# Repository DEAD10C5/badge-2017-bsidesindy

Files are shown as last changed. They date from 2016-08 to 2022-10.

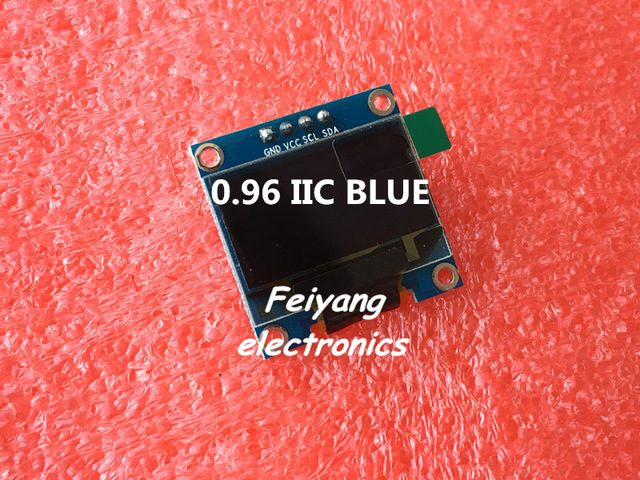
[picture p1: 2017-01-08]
image/1pcs-0-96-blue-0-96-inch-OLED-module-New-128X64-OLED-LCD-LED-Display-Module.jpg_640x640.jpg

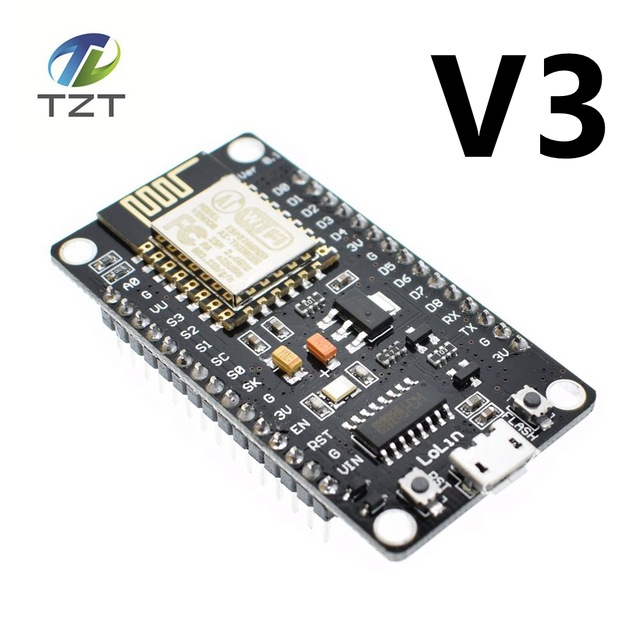
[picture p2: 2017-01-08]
image/1PCS-Wireless-module-CH340-NodeMcu-V3-Lua-WIFI-Internet-of-Things-development-board-based-ESP8266.jpg_640x640.jpg

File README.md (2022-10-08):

## BSidesIndy 2017 Badge



We did this as a workshop during @indybsides in March 2017.

See the wiki for more information.

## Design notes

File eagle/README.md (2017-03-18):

###
https://learn.sparkfun.com/tutorials/using-eagle-schematic

### push buttons
 https://www.sparkfun.com/products/97

I have ordered a bunch of this push buttons. These push buttons fit easily into a breadboard. However, now that I have my prototype working and I am making a schematic in Eagle, I have no idea what the dimensions are to make my switch component in Eagle. It is very frustrating and time wasting.
 M-Short / about 2 years ago /  1
This switch is actually in our Eagle libraries. Check under the Electromagnetic/Switch-Momentary-2 section. It should be the first one (Description: Omron switch). Or internal part number is SWCH-8441, as long as you have that one selected you should be good. Feel free to email techsupport if you have any other questions or ever need more information.

### esp-8266

* Clone the repo :

https://github.com/nodemcu/nodemcu-devkit-v1.0

Copy the file ESP12E_DEVKIT.lbr from the repo to the folder /Applications/EAGLE-7.5.0/lbr

Open the brd file, click "Library" then "use"

### OLED SSD-1306

http://learn.acrobotic.com/tutorials/post/esp8266-oled-display-using-i2c

### resistors (using internal instead)

http://electronics.stackexchange.com/questions/65015/resistor-and-capacitor-package-types-eagle-cad

Resistors with different power ratings have different standard sizes (for example, 1/8W vs 1/4W). Likewise for capacitors, the part you need to use depends on the type of capacitor (monolithic, ceramic, electrolytic, etc) and the capacitance and voltage ratings. Assuming you are looking at the RCL library, 0207/10 simply means the body of the resistor is 2mm x 7mm and the hole to hole spacing is 10mm. Similarly C050-035x075 means 5mm hole spacing, 3.5mm x 7.5mm outline. You have to figure out (with calipers, for example) if this will work with the parts you are planning to use.

http://www.instructables.com/id/Draw-Electronic-Schematics-with-CadSoft-EAGLE/step5/Add-resistors/

### battery holder

https://www.sparkfun.com/products/13113
Note: This part can be found in the Electromechanical Eagle library under ‘Battery18650’.

### some notes

One thing you can do is print the board layout at 1:1 scale on paper before sending it out to the fab to see if the parts fit. You can catch common errors this way.

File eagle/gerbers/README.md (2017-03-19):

## Create Gerber files
http://www.build-electronic-circuits.com/gerber-file/

## view gerber files
http://www.gerber-viewer.com/

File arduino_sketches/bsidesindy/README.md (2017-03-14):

** Arduino code for Nodemcu esp-12e
https://www.arduino.cc/en/Tutorial/TFTPong

http://www.coagula.org/albedo/tutorial-manage-menu-and-lcd-display-with-arduino/

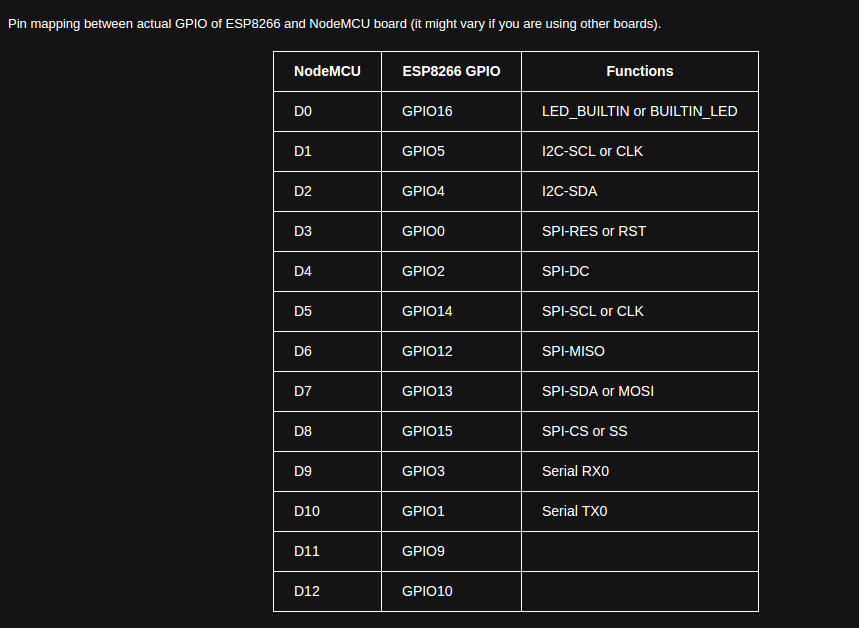
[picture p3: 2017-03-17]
image/esp12-e_pinout.png

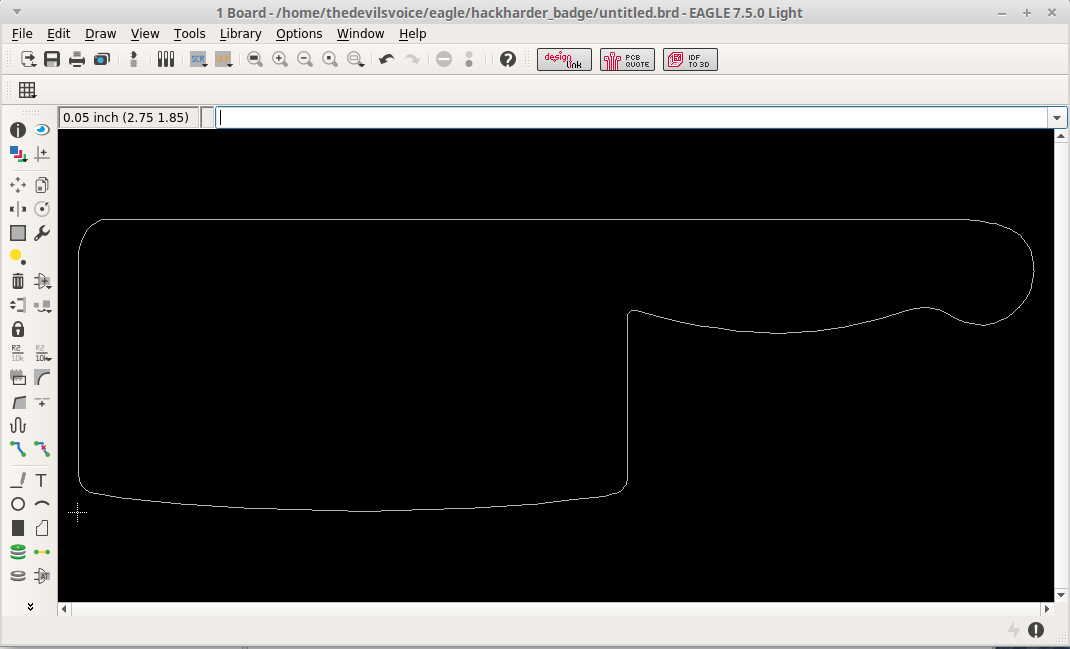
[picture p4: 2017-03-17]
image/board-1.png

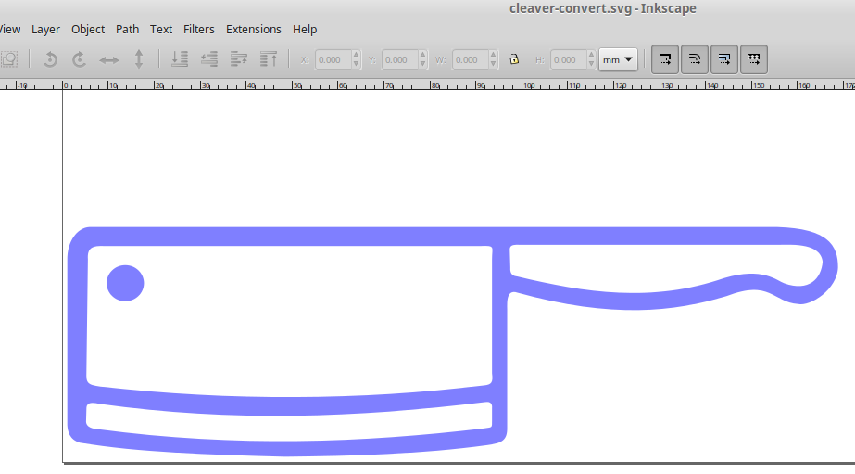
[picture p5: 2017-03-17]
image/Screenshot-1.png

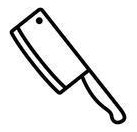
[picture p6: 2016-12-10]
image/cleaver.jpg

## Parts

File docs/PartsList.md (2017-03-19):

# Required Badge parts

use the links provded to order the ESP8266 and the OLED so it matches up to the holes in the PCB.
The battery and case are available on ebay. These will be stuck to the back of the board using the VHB tape, which is available from amazon or target stores.

| count | part | est cost |
| --- | --- | --- |
| 1 | [NodeMCU LUA WiFi Internet Development Board V3 Wireless module Based CH340 ESP8266 EK1677 Arduino Compatible]( https://smile.amazon.com/gp/product/B010O1G1ES/ )| $9 |
| 1 | [ OLED screen](https://www.amazon.com/gp/product/B00O2KDQBE) | $9 | 
| 4 | [switches]( http://www.digikey.com/product-detail/en/te-connectivity-alcoswitch-switches/1825910-6/450-1650-ND/1632536 ) | $0.10 |
| 1 | [battery holder](https://www.sparkfun.com/products/13113) | $ 0.75 |

# Prototyping Supplies

These are optional pieces, only one breadboard is needed. 

| count | part | est cost |
| --- | --- | --- |
| 1 | [ Large breadboard] ( https://www.adafruit.com/products/443 )  | $20 |
| 1 | [ VHB tape for battery/back of OLED ] (https://www.amazon.com/Tape-RP32-width-length-Roll/dp/B007Y7E0CQ) | $3 |
| 1 | micro USB cable to program ESP8266 | $5 | 
| 1 | [ small breadboard] (  https://www.adafruit.com/products/64 ) | $5 | 
| 1 | [ Jumper wires] ( https://www.adafruit.com/products/153 ) | $6 | 

# Alternate Sources

| count | part | est cost |
| --- | --- | --- |
| 1 | [Blue 0.96 inch 128X64 OLED LCD LED Display Module For arduino IIC I2C Communicate] (https://m.aliexpress.com/s/item/32697483355.html ) | $3 | 
| 1 | 18650 3.7V/12000mAh Rechargeable Li-ion Battery | $5 |

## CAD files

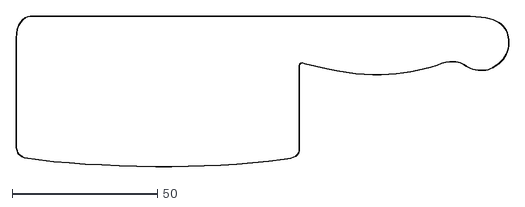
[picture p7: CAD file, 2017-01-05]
image/cleaver-outline.dxf
169.7 x 51.9

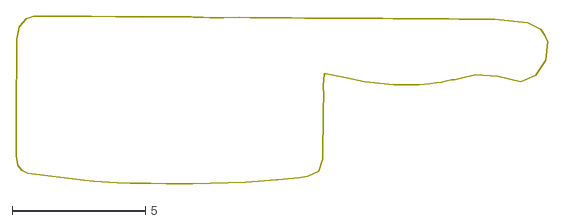
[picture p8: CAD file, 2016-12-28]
image/cleaver-ki2.dxf
20.0 x 6.30

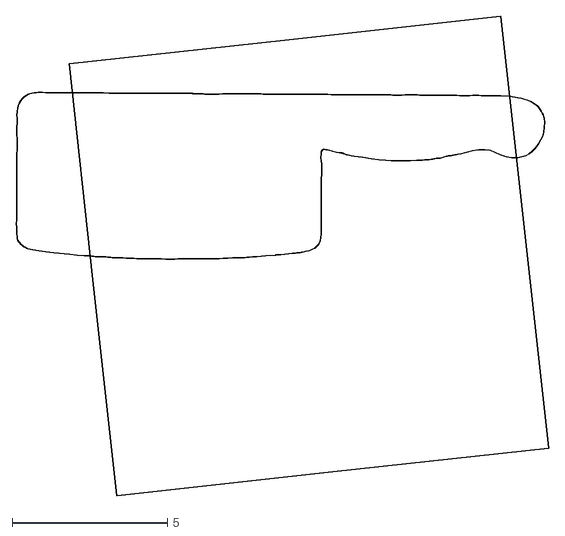
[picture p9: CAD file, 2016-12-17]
image/cleaver.dxf
17.2 x 15.5

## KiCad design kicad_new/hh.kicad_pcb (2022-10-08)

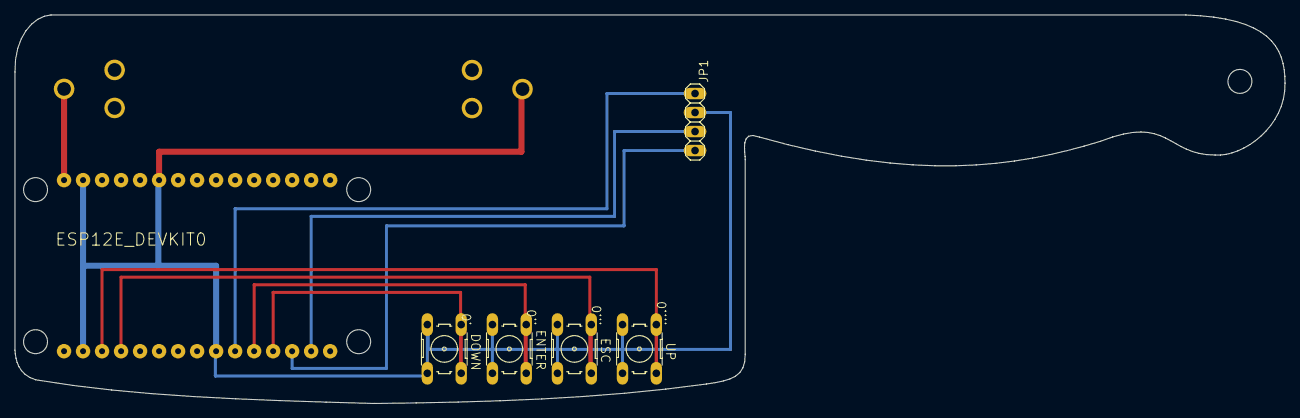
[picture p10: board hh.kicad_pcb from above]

Board: 6 copper layers, 169.7 x 51.9 mm, 8 parts (1 on the bottom side), 9 nets.

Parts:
.0, ..0, ...0, ....0: B3F-10XX
@HOLE0: (no value)
BT1: BATTERY_18650-HOLDER
ESP12E_DEVKIT0: ESP12E_DEVKIT
JP1: OLED; 1X04

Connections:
unnamed: .0.3, .0.4, ..0.3, ..0.4, ...0.3, ...0.4, ....0.3, ....0.4, BT1.GND@1, ESP12E_DEVKIT0.GND@0, ESP12E_DEVKIT0.GND@1, ESP12E_DEVKIT0.GND@2, ESP12E_DEVKIT0.GND@3, JP1.2
unnamed: .0.1, .0.2, ESP12E_DEVKIT0.D3
unnamed: ESP12E_DEVKIT0.3V3@1, JP1.1
unnamed: BT1.PWR@1, ESP12E_DEVKIT0.VIN
unnamed: ESP12E_DEVKIT0.D1, JP1.3
unnamed: ESP12E_DEVKIT0.D2, JP1.4
unnamed: ..0.1, ..0.2, ESP12E_DEVKIT0.D4
unnamed: ...0.1, ...0.2, ESP12E_DEVKIT0.RX
unnamed: ....0.1, ....0.2, ESP12E_DEVKIT0.TX

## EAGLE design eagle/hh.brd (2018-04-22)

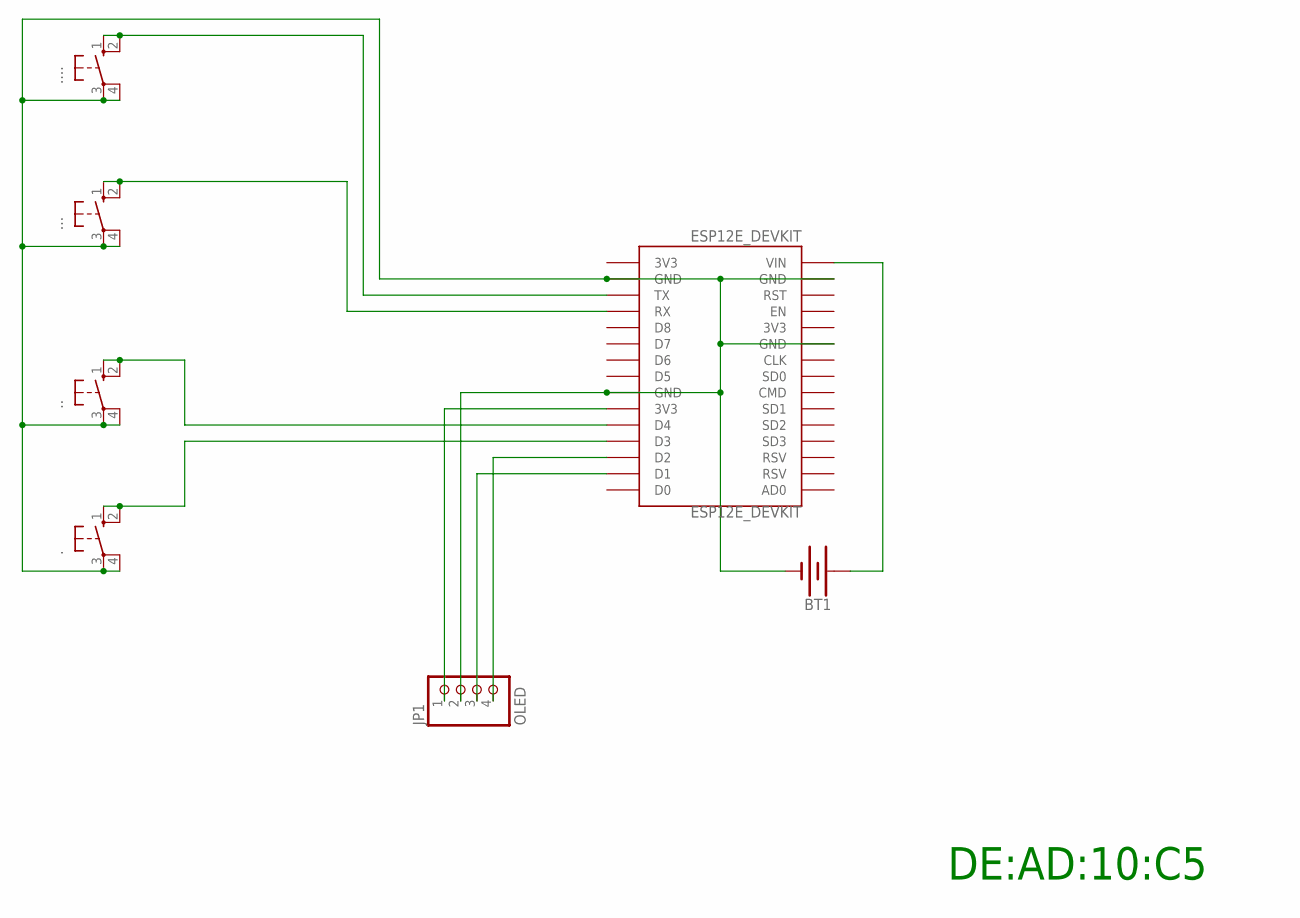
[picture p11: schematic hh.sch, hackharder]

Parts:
., .., ..., ....: 10-XX; B3F-10XX
BT1: BATTERY-18650; BATTERY_18650-HOLDER
ESP12E_DEVKIT: ESP12E_DEVKIT
JP1: OLED; 1X04

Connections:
unnamed: ..3, ..4 (P1), ...3, ...4 (P1), ....3, ....4 (P1), .....3, .....4 (P1), BT1.GND@1 (-), ESP12E_DEVKIT.GND@0 (GND), ESP12E_DEVKIT.GND@1 (GND), ESP12E_DEVKIT.GND@2 (GND), ESP12E_DEVKIT.GND@3 (GND), JP1.2
unnamed: ..1 (S), ..2 (S1), ESP12E_DEVKIT.D3
unnamed: ESP12E_DEVKIT.3V3@1 (3V3), JP1.1
unnamed: BT1.PWR@1 (+), ESP12E_DEVKIT.VIN
unnamed: ESP12E_DEVKIT.D1, JP1.3
unnamed: ESP12E_DEVKIT.D2, JP1.4
unnamed: ...1 (S), ...2 (S1), ESP12E_DEVKIT.D4
unnamed: ....1 (S), ....2 (S1), ESP12E_DEVKIT.RX
unnamed: .....1 (S), .....2 (S1), ESP12E_DEVKIT.TX

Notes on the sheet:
DE:AD:10:C5

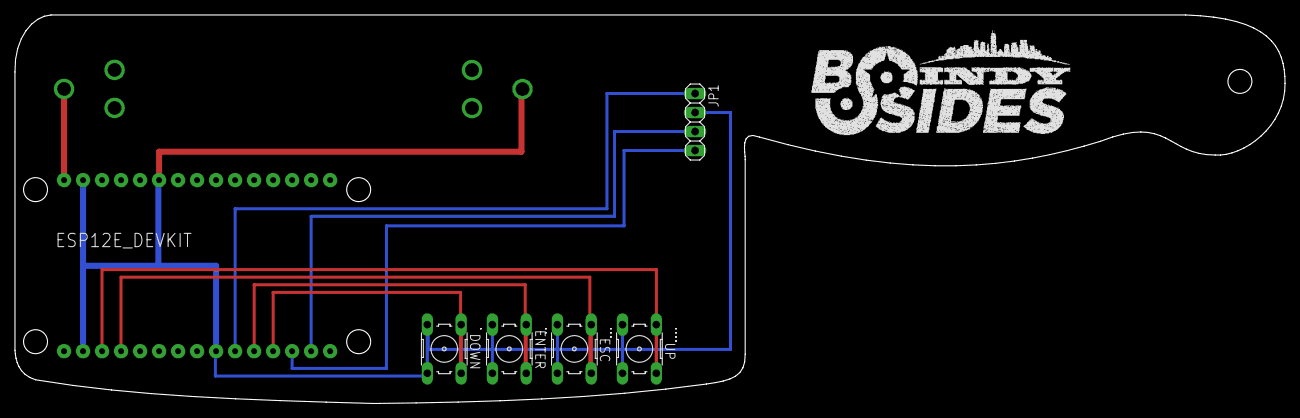
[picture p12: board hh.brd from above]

Board: 2 copper layers, 169.7 x 51.9 mm, 7 parts (1 on the bottom side), 9 nets.

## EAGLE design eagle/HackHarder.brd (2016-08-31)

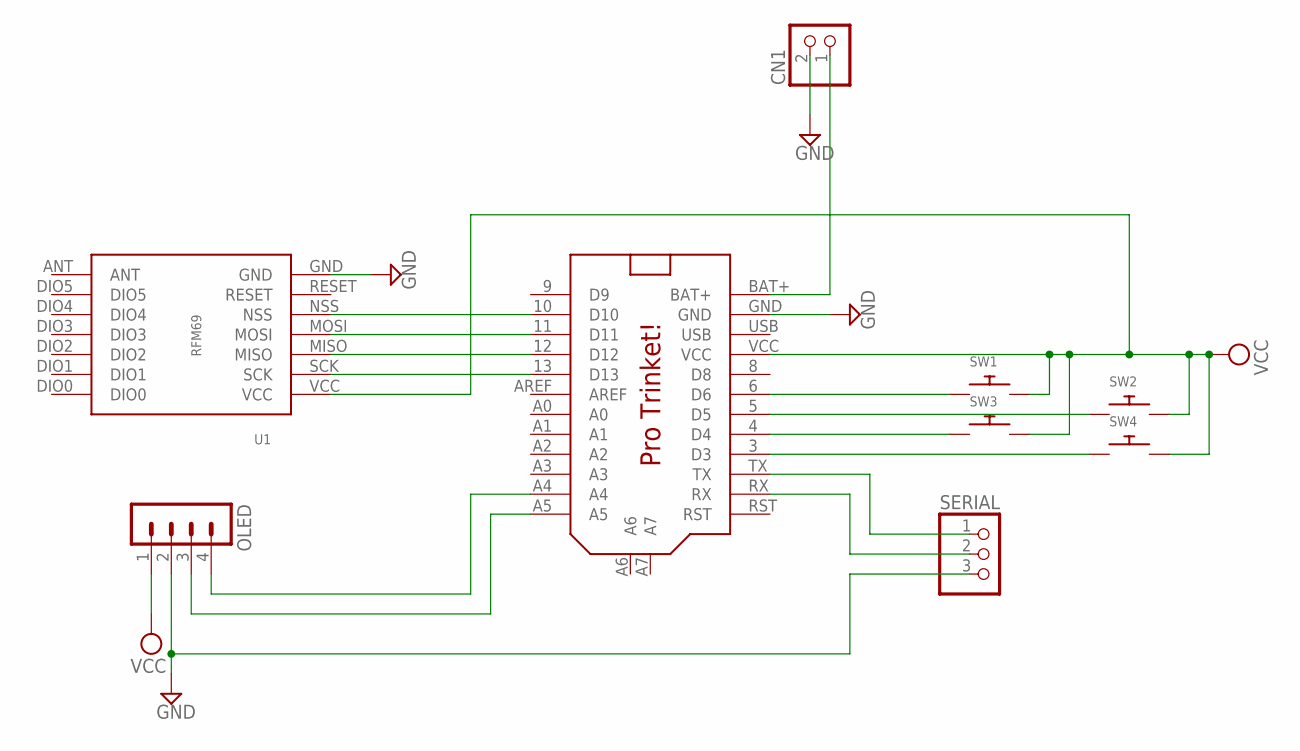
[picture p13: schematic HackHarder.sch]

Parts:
CN1: JST_2PIN-SMT-RA; JST-PH-2-SMT-RA
MCU1: PRO_TRINKET; PROTRINKET
OLED: MA04-1
SERIAL: PINHD-1X3; 1X03
SW1, SW2, SW3, SW4: SWITCH_PUSHBUTTONEVQ-PE; TACT_PANA-EVQ
U1: RFM69HW; RFM69_PADS

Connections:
G$1: CN1.2 (1), MCU1.GND, OLED.2, SERIAL.3, U1.GND
unnamed: CN1.1 (2), MCU1.BAT+
unnamed: MCU1.A5, OLED.3
unnamed: MCU1.A4, OLED.4
unnamed: MCU1.11 (D11), U1.MOSI
unnamed: MCU1.12 (D12), U1.MISO
unnamed: MCU1.13 (D13), U1.SCK
unnamed: MCU1.10 (D10), U1.NSS
unnamed: MCU1.6 (D6), SW1.P$1
unnamed: MCU1.5 (D5), SW2.P$1
unnamed: MCU1.4 (D4), SW3.P$1
unnamed: MCU1.3 (D3), SW4.P$1
unnamed: MCU1.TX, SERIAL.1
unnamed: MCU1.RX, SERIAL.2
USB: MCU1.USB
VCC: MCU1.VCC, OLED.1, SW1.P$2, SW2.P$2, SW3.P$2, SW4.P$2, U1.VCC

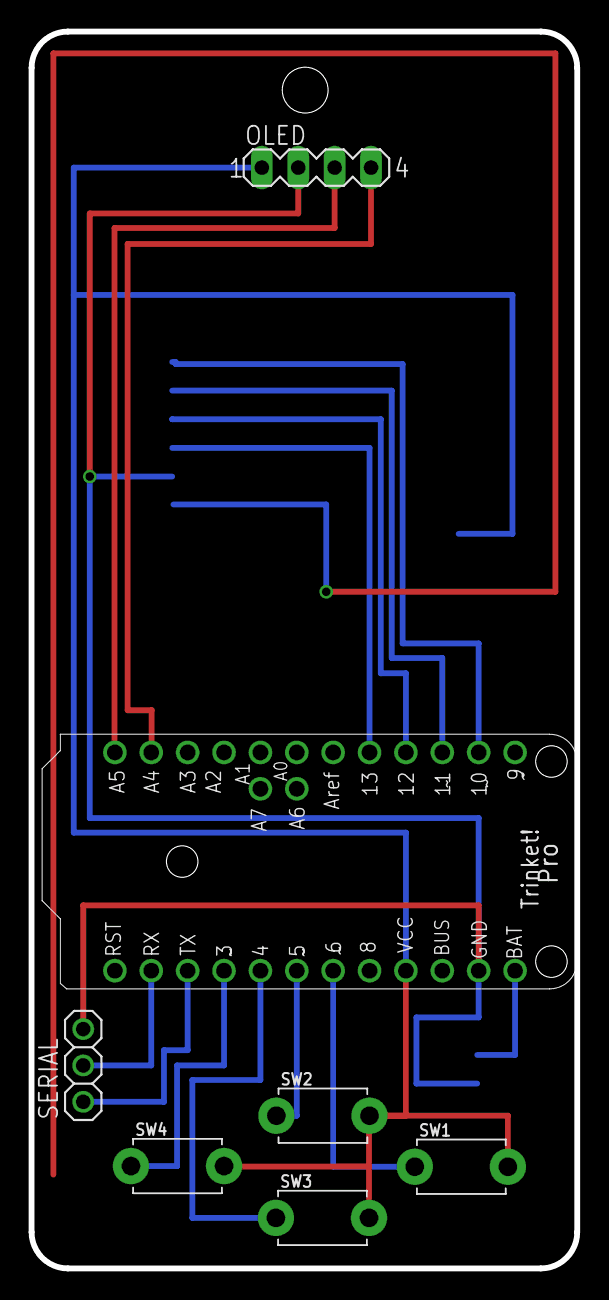
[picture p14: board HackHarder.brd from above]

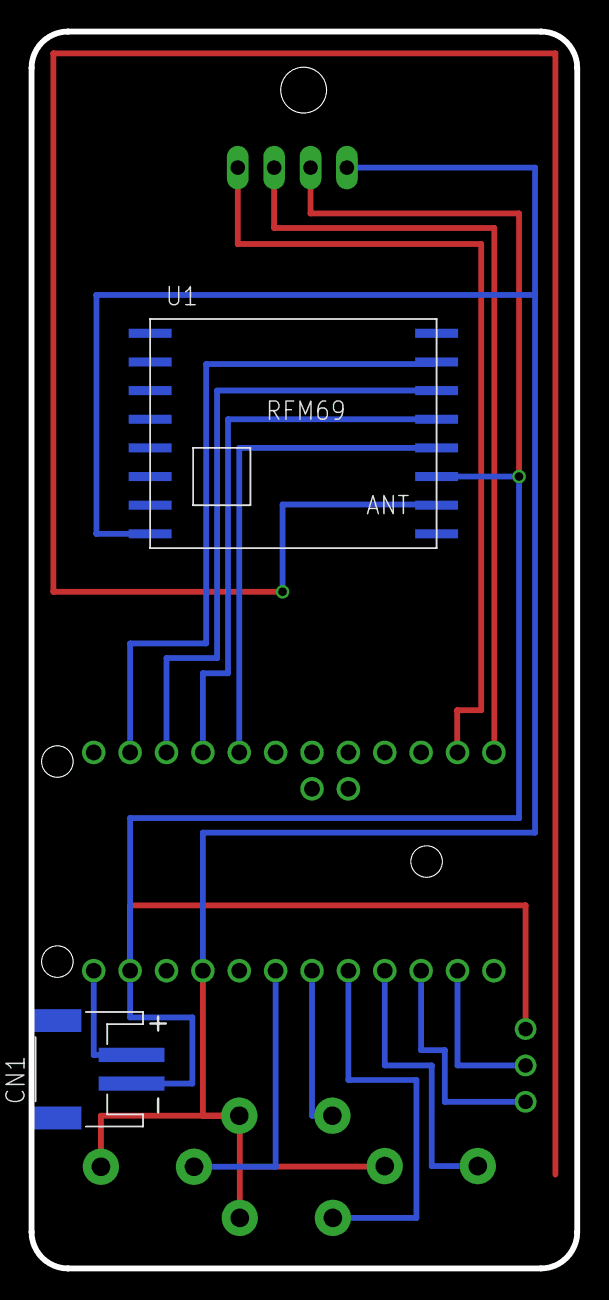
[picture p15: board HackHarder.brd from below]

Board: 2 copper layers, 38.1 x 86.4 mm, 9 parts (2 on the bottom side), 15 nets.

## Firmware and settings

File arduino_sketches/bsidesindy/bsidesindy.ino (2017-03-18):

/* 
 *   ____  _           _       _         _     _           
 *  / __ \(_)_ __   __| |_   _| |__  ___(_) __| | ___  ___ 
 * / / _` | | '_ \ / _` | | | | '_ \/ __| |/ _` |/ _ \/ __|
 *| | (_| | | | | | (_| | |_| | |_) \__ \ | (_| |  __/\__ \
 * \ \__,_|_|_| |_|\__,_|\__, |_.__/|___/_|\__,_|\___||___/
 *  \____/               |___/                             
 *
 *              H dlh dcaego uz aego ak.vol,vohs
 */
#include <ESP8266WiFi.h>
#include "Adafruit_MQTT.h"
#include "Adafruit_MQTT_Client.h"
// These next 4 are to drive the OLED
#include <SPI.h>
#include <Wire.h>
#include <Adafruit_GFX.h>
#include <Adafruit_SSD1306.h>


// Defines for LED pulse code
#define BRIGHT    350     //max led intensity (1-500)
#define INHALE    1250    //Inhalation time in milliseconds.
#define PULSE     INHALE*1000/BRIGHT
#define REST      100    //Rest Between Inhalations.

/*
 * Adafruit.io Setup 
 * 
 * Use this to connect to https://io.adafruit.com/
 * rather than a local MQTT service. 
 * 
 * Create an ESP8266 WiFiClient class to connect to the MQTT server. 
 * WiFiClient client; or... use WiFiFlientSecure for SSL
 * 
 */
#define AIO_SERVER "io.adafruit.com"
#define AIO_SERVERPORT  8883                   // use 8883 for SSL
#define AIO_USERNAME    ""
#define AIO_KEY         ""
WiFiClientSecure client;
// Setup the MQTT client class by passing in the WiFi client and MQTT server and login details.
Adafruit_MQTT_Client mqtt(&client, AIO_SERVER, AIO_SERVERPORT, AIO_USERNAME, AIO_KEY);



/* 
 * Global Variables Setup 
 */
char handle[ ] = "p0lr";
char input[ ] = "";
bool inputComplete = false;
const char* ssid = "batpack";
const char* password = "batpack";
//const char* mqtt_server = "broker.mqttdashboard.com";
//const char* mqtt_server = "iot.eclipse.org";
//const char* mqtt_server = "io.adafruit.com"
#define OLED_RESET 2
Adafruit_SSD1306 display(OLED_RESET);
int switchPin1 = D9;              
int switchPin2 = D10;
int switchPin3 = D4;
int switchPin4 = D3;

/****************************** Feeds ***************************************/
Adafruit_MQTT_Publish toServer = Adafruit_MQTT_Publish(&mqtt, AIO_USERNAME "/feeds/toServer");
Adafruit_MQTT_Subscribe toBadge = Adafruit_MQTT_Subscribe(&mqtt, AIO_USERNAME "/feeds/toBadge");

/*************************** Sketch Code ************************************/

/*  
 * Bug workaround for Arduino 1.6.6, it seems to need a function declaration 
 * for some reason (only affects ESP8266, likely an arduino-builder bug).
 */
void MQTT_connect();

#if (SSD1306_LCDHEIGHT != 32)
#error("Height incorrect, please fix Adafruit_SSD1306.h!");
#endif

void setup() {
  Serial.begin(115200);
  delay(10);
  setup_display();
  setup_wifi();
  pinMode(switchPin1,       INPUT);  // Set the switch pin as input
  digitalWrite(switchPin1,  HIGH);   // turn on pull up resistor
  pinMode(switchPin2,       INPUT);
  digitalWrite(switchPin2,  HIGH);
  pinMode(switchPin3,       INPUT);
  digitalWrite(switchPin3,  HIGH);
  pinMode(switchPin4,       INPUT);
  digitalWrite(switchPin4,  HIGH);
  pinMode(LED_BUILTIN,      OUTPUT); // initialize the on-board LED
  digitalWrite(LED_BUILTIN, HIGH);   // turn LED off
  mqtt.subscribe(&toBadge);          // Setup MQTT subscription for onoff feed.
}

void loop() {
  int status;
  display.setCursor(0, 0);
  display.println("@indybsides");
  display.display();
  
  MQTT_connect();
  Adafruit_MQTT_Subscribe *subscription;
  while ((subscription = mqtt.readSubscription(5000))) {
    if (subscription == &toBadge) {
      Serial.println((char *)toBadge.lastread);
    }
  }

  // check if the button is pressed
  if (digitalRead(switchPin1) == LOW) {               
    button_press("1");
  } else if (digitalRead(switchPin2) == LOW) {
    button_press("2");
  } else if (digitalRead(switchPin3) == LOW) {
    button_press("3");
  } else if (digitalRead(switchPin4) == LOW) {
    button_press("4");
  }
  else {

    Serial.println("Nothing just happened");
  }
  
  //Check to see if there is any serial data inbound
  if (Serial.available() > 0) {
  // read the incoming byte:
    char inChar[ ] = "";
    inChar[0] = (char)Serial.read();
    strcat(input, inChar);
    if (inChar[0] == '\n') {
      inputComplete = true;
    }
  }

  // Now we can publish stuff!
  if (inputComplete) {
    //digitalWrite(LED_BUILTIN, HIGH);
    char post[ ] = "";
    strcat(post, handle);
    strcat(post, ": ");
    strcat(post, "Hello, World!");
    Serial.println(post);
    if (! toServer.publish(post)) {
      Serial.println(F("Failed"));
    } else {
//      input = " ";
      inputComplete = false;
    }
  }
  // ping the server to keep the mqtt connection alive
  // NOT required if you are publishing once every KEEPALIVE seconds
  if(! mqtt.ping()) {
    mqtt.disconnect();
  }
}

void setup_display() {
  // by default, we'll generate the high voltage from the 3.3v line 
  // internally! (neat!)
  // initialize with the I2C addr 0x3C (for the 128x32)
  display.begin(SSD1306_SWITCHCAPVCC, 0x3C);  
  display.clearDisplay();
  display.setTextSize(1);
  display.setTextColor(WHITE);
  display.setCursor(0,0);  
}

void setup_wifi() {
  delay(100);
  Serial.print("Connecting to ");
  Serial.println(ssid);
  WiFi.begin(ssid, password);
    while (WiFi.status() != WL_CONNECTED) 
    {
      delay(500);
      Serial.print(".");
    }
  randomSeed(micros());
  String msg="WiFi Connected!\nIP address: " + WiFi.localIP();
  Serial.println(msg);
  display.println(msg);
  display.display();
}

/* 
 * Function to connect and reconnect as necessary to the MQTT server.
 * Should be called in the loop function and it will take care if connecting.
 * 
 */
void MQTT_connect() {
  int8_t ret;

  // Stop if already connected.
  if (mqtt.connected()) {
    return;
  }

  String msg="Connecting to MQTT... ";
  Serial.println(msg);
  display.println(msg);
  display.display();
  
  uint8_t retries = 3;
  while ((ret = mqtt.connect()) != 0) { // connect will return 0 for connected
       Serial.println(mqtt.connectErrorString(ret));
       Serial.println("Retrying MQTT connection in 5 seconds...");
       mqtt.disconnect();
       delay(5000);  // wait 5 seconds
       retries--;
       if (retries == 0) {
         // basically die and wait for WDT to reset me
         while (1);
       }
  }
  msg = "MQTT Connected!";
  Serial.println(msg);
  display.println(msg);
  display.display();
  
}

void button_press(String button_num) {
  //digitalWrite(LED_BUILTIN, LOW);   // turn LED on
  String msg = "Button " + button_num + " pressed";
  Serial.println(msg);
  display.println(msg);
  display.display();
  led_half_breath();
  delay(300);
  //digitalWrite(LED_BUILTIN, HIGH);  // turn LED off
  digitalWrite(switchPin1, HIGH);
  digitalWrite(switchPin2, HIGH);
  digitalWrite(switchPin3, HIGH);
  digitalWrite(switchPin4, HIGH);
  delay(200);
  display.setCursor(0, 4);
  display.clearDisplay();
  display.display();
}

/*
 * Pulse the Internal LED
 */
void led_breath() {
     //ramp increasing intensity, Inhalation: 
  for (int i=1;i<BRIGHT;i++){
    digitalWrite(LED_BUILTIN, LOW);          // turn the LED on.
    delayMicroseconds(i*10);         // wait
    digitalWrite(LED_BUILTIN, HIGH);         // turn the LED off.
    delayMicroseconds(PULSE-i*10);   // wait
    delay(0);                        //to prevent watchdog firing.
  }
}

/*
 * Half-pulse the internal LED
 */
void led_half_breath() {
  
  //ramp decreasing intensity, Exhalation (half time):
  for (int i=BRIGHT-1;i>0;i--){
    digitalWrite(LED_BUILTIN, LOW);          // turn the LED on.
    delayMicroseconds(i*10);          // wait
    digitalWrite(LED_BUILTIN, HIGH);         // turn the LED off.
    delayMicroseconds(PULSE-i*10);  // wait
    i--;
    delay(0);                        //to prevent watchdog firing.
  }
  delay(REST);                       //take a rest...
}

/***************************************************
  Adafruit MQTT Library ESP8266 Example

  Must use ESP8266 Arduino from:
    https://github.com/esp8266/Arduino

  Works great with Adafruit's Huzzah ESP board & Feather
  ----> https://www.adafruit.com/product/2471
  ----> https://www.adafruit.com/products/2821

  Adafruit invests time and resources providing this open source code,
  please support Adafruit and open-source hardware by purchasing
  products from Adafruit!

  Written by Tony DiCola for Adafruit Industries.
  MIT license, all text above must be included in any redistribution
 ********************************************************************
This is an example for our Monochrome OLEDs based on SSD1306 drivers

  Pick one up today in the adafruit shop!
  ------> http://www.adafruit.com/category/63_98

This example is for a 128x32 size display using I2C to communicate
3 pins are required to interface (2 I2C and one reset)

Adafruit invests time and resources providing this open source code, 
please support Adafruit and open-source hardware by purchasing 
products from Adafruit!

Written by Limor Fried/Ladyada  for Adafruit Industries.  
BSD license, check license.txt for more information
All text above, and the splash screen must be included in any redistribution
*********************************************************************/

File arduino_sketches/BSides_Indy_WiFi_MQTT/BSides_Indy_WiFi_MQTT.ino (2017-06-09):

#include "SSD1306.h" // alias for `#include "SSD1306Wire.h"`
#include "ESP8266WiFi.h"
#define UP 1
#define ESC 3
#define ENTER 2
#define DOWN 0
SSD1306 display(0x3c, D2, D1);

void setup() {
  display.init();
  display.flipScreenVertically();
  WiFi.mode(WIFI_STA);
  WiFi.disconnect();
  pinMode(UP, INPUT_PULLUP);
  pinMode(ESC, INPUT_PULLUP);
  pinMode(ENTER, INPUT_PULLUP);
  pinMode(DOWN, INPUT_PULLUP);
}

void loop() {
  if(WiFi.status() == 3) {

  }
  else {
    WiFi.begin("badger", "!dongle!");
    while (WiFi.status() != 3) {
      display.clear();
      display.setTextAlignment(TEXT_ALIGN_LEFT);
      display.setFont(ArialMT_Plain_10);
      display.drawString(0, 0, "Connecting to WiFi");
      display.display();
    }
    display.clear();
    display.setTextAlignment(TEXT_ALIGN_LEFT);
    display.setFont(ArialMT_Plain_10);
    display.drawString(0, 0, "WiFi Connected");
    display.drawString(0, 10, String(WiFi.localIP()[0]) + "." + String(WiFi.localIP()[1]) + "." + String(WiFi.localIP()[2]) + "." + String(WiFi.localIP()[3]));
    display.display();
  }
}
/**
 * The MIT License (MIT)
 *
 * Copyright (c) 2016 by Daniel Eichhorn
 *
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
 */

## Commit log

2016-08-17 Badge Files
    Initial Eagle Badge Files
    [HackHarder.brd, HackHarder.sch]
2016-08-30 Add files via upload
    Updated board with smaller footprint
    [HackHarder.brd, HackHarder.sch]
2016-08-31 Add files via upload
    Latest version
    [HackHarder.brd, HackHarder.sch]
2016-08-31 Add files via upload
    Now with serial breakout! I'm not sure that the footprint for the radio is correct - need to double-check the pintout on the module spec sheet...
    [HackHarder.brd, HackHarder.sch]
2016-12-10 badge pcb art
    [cleaver.dxf, cleaver.jpg.dxf]
2016-12-10 minor updates
    [cleaver.jpg.dxf]
2016-12-17 pcb updates
    [cleaver.dxf]
2016-12-28 graphics updates
    [HackHarder.brd, HackHarder.sch, cleaver-ki2.dxf]
2017-01-05 Created outline and silkscreen artwork, imported both to kicad and created board
    [cleaver-outline.dxf, hh.kicad_pcb]
2017-01-08 eagle schematic
    [hh.sch]
2017-02-27 Update PartsList.md
    added micro USB cable
2017-03-01 add sample arduino code
2017-03-03 refactoring, added first button
2017-03-05 button test sketch
2017-03-13 updates to eagle files
    [hh.brd, hh.sch]
2017-03-16 design updates
    [HackHarder.brd, HackHarder.sch, hh.brd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]
2017-03-17 Update README.md
    added battery holder info
2017-03-17 images and brd update
    [hh.brd, hh.sch]
2017-03-17 revise component placement in eagle
    [hh.brd]
2017-03-17 add silkscreen text in eagle
    [hh.brd]
2017-03-17 wiring 1
    [hh.brd, hh.sch]
2017-03-17 wiring 2
    [hh.brd, hh.sch]
2017-03-17 fix eagle drc error
    [hh.brd]
2017-03-18 testing final design
    [hh.brd, hh.sch]
2017-03-18 Added battery clips, fixed VIN, moved switches closer together to accommodate the battery clips, added a ground plane under the radio.
    [hh.brd, hh.sch]
2017-03-18 arduino sketch cleanup
2017-03-18 Update PartsList.md
    changed battery holder
2017-03-18 Update README.md
    change battery holder
2017-03-19 Add files via upload
    Latest Update
    [hh.brd]
2017-03-19 gerber files
    [hh.brd]
2017-03-19 Update PartsList.md
    change OLED source, must have Vcc pin on far left
2017-03-19 silkscreen updates
    [hh.brd]
2017-03-19 silkscreen placement
    [hh.brd]
2017-03-19 Major changes to placement of components
    [hh.brd, hh.sch]
2017-03-19 Trace Revisions
    [hh.brd]
2017-03-19 silkscreen edits
    [hh.brd, hh.sch]
2017-03-19 Artwork
    Added BSides Indy artwork
    [hh.brd]
2017-03-19 Modified switch labels
    [hh.brd]
2017-04-03 Code Update
    Allows you to scan for WiFi networks, scroll through the networks
    (UP/DOWN buttons), re-scan networks (ESC button), and connect to a
    network with open authentication (ENTER button)
2017-04-03 Better WiFi error handling
    Better WiFi error handling
    [BSides_Indy_WiFi_Scan.ino]
2017-04-04 Allow to disconnect after WiFi is connected
    Pressing ESC during or after WiFi connection will re-scan and allow you
    to connect to another network.
2018-04-04 cleanup first release
    [hh.GBL, hh.GBO, hh.GBP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]
2022-10-08 convert eagle to KiCAD (#5)
    [hh.kicad_pcb, hh.kicad_sch]

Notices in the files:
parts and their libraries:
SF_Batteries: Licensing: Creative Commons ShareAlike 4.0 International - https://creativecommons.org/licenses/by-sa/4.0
